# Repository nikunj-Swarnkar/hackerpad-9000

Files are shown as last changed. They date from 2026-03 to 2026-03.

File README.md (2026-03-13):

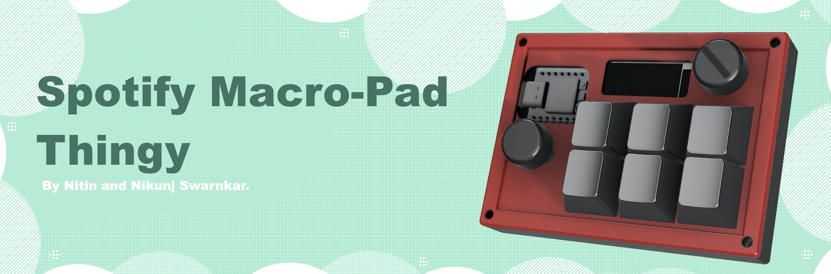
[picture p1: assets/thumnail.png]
thunail


# Spotify Marcro-pad Thingy







A custom key macropad with two rotating dials, 6 customisable keys, and an OLED screen. Basically my iteration of the Spotify car thing — but for your desk.

**Project by [nikunj-Swarnkar](https://github.com/nikunj-Swarnkar)** — Firmware by [Nitin-2468-dev](https://github.com/Nitin-2468-dev)

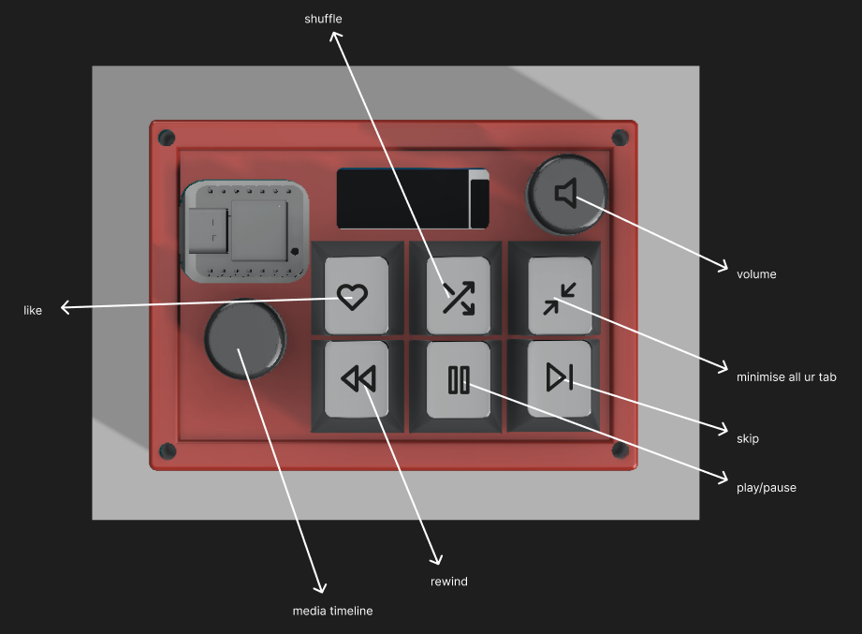
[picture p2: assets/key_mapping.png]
Key mapping


---

## Features

- Two-part case, easy to assemble
- 128×32 OLED display
- 2 × EC11 rotary encoders
- 4 heat-set inserts and bolted case
- 6 mechanical keys

---

## CAD Model

Made in Fusion360. Everything fits together using 4 × M3 bolts and heat-set inserts. The case has two parts: a main body and a front lid.

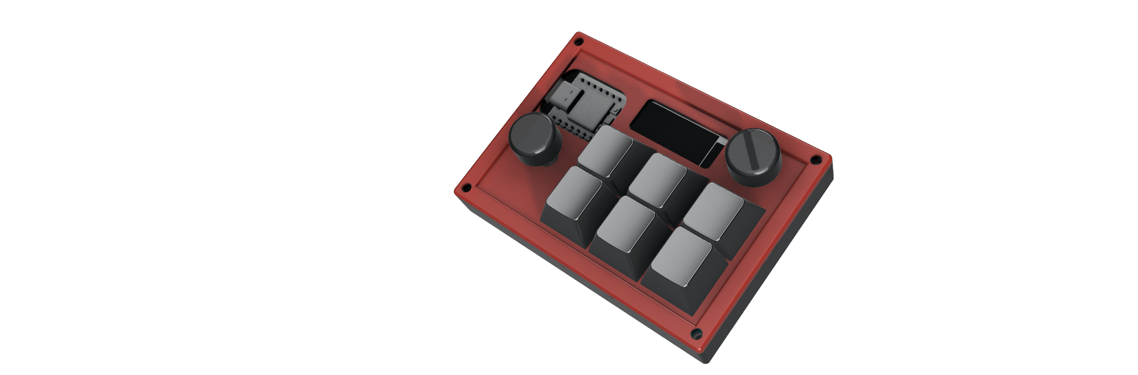
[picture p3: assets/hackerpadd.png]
CAD model


---

## PCB

Made in KiCad.

**Schematic**

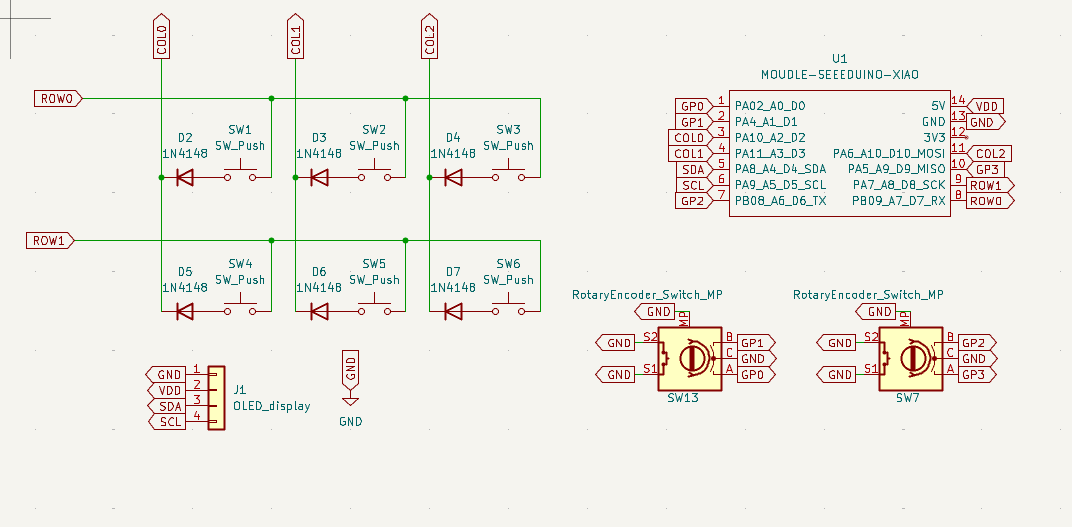
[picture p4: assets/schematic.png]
Schematic


**PCB**

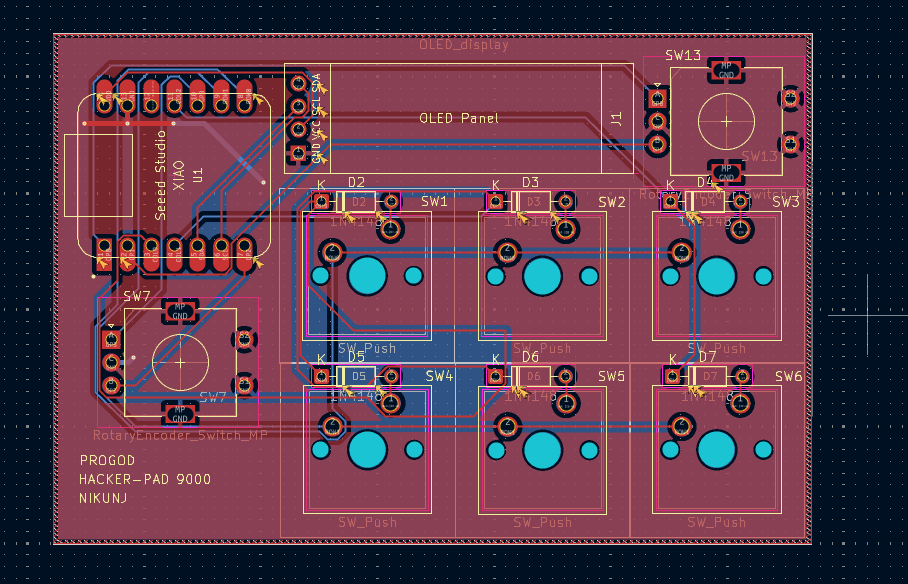
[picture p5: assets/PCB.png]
PCB


Uses MX-style key switches.

---

## Firmware Overview

The Spotify Marcro-pad Thingy runs **[KMK firmware](https://github.com/KMKfw/kmk_firmware)** on a **[Seeed XIAO RP2040](https://wiki.seeedstudio.com/XIAO-RP2040/)**, paired with a **Python bridge application** that connects Spotify playback data to the keyboard over USB. The device behaves like a mini StreamDeck dedicated to music control.

### Playback Controls

| Key | Action |
| --- | --- |
| Play/Pause | Toggle playback |
| Next | Next track |
| Previous | Previous track  |
| Shuffle | Toggle shuffle  |
| Repeat | Toggle repeat |
| Mute | Set volume to 0 |

### Encoder Controls

| Encoder | Function |
| --- | --- |
| Encoder 1 | Track timeline |
| Encoder 2 | Volume |

### Key Layout

```
[ Like ]     [ Shuffle ]    [ Minimize ]
[ Rewind ]   [ Play/Pause ] [ Skip ]
```

---

## OLED Display

### Spotify Screen

```
Spotify
Blinding Lights
████░░░░░░ 1:42
```

Displays song title, playback progress bar, and current playback time.

### Volume Screen

```
Volume
██████░░░░ 60%
```

Displayed when adjusting volume.

### Idle Screen

An animated BongoCat appears when nothing is playing.

---

## Album Art Rendering

Album art is fetched from Spotify and processed by the bridge:

1. Download image
2. Resize to 32×32
3. Convert to monochrome
4. Send bitmap to keyboard

The OLED displays the artwork beside the track information.

---

## System Architecture

```
Spotify App
      ↓
Spotify Web API
      ↓
spotify_bridge.exe (Python)
      ↓
USB Serial
      ↓
KMK Firmware
      ↓
Macropad Hardware
      ↓
OLED Display + Controls
```

The bridge application handles Spotify API communication; the firmware handles hardware interaction.

---

## Serial Protocol

Communication between the firmware and bridge uses a lightweight text protocol:

```
SONG|title|artist|position|duration|tempo
VOL|70
IDLE
COVER|bitmap_data
CMD|NEXT
CMD|PLAY
CMD|SEEK|120
```

---

## Firmware

Written using **KMK (Keyboard Module Kit)** on CircuitPython. Main file: `CIRCUITPY/code.py`

**Responsibilities:**

- Scan key matrix
- Handle rotary encoders
- Communicate with bridge over USB
- Render OLED interface
- Control RGB lighting

### Pin Mapping

**Matrix**

| Function | Pin |
| --- | --- |
| COL 0 | D2 / GP28 |
| COL 1 | D3 / GP29 |
| COL 2 | D10 / GP3 |
| ROW 0 | D7 / GP1  |
| ROW 1 | D8 / GP2  |

**Encoder 1 — Volume**

| Signal | Pin |
| --- | --- |
| A | D0 / GP26 |
| B | D1 / GP27 |

**Encoder 2 — Track Scrub**

| Signal | Pin |
| --- | --- |
| A | D6 / GP0 |
| B | D9 / GP4 |

**OLED**

| Signal | Pin |
| --- | --- |
| SDA | D4 / GP6 |
| SCL | D5 / GP7 |

**RGB LEDs:** DATA → D0 / GP26

---

## Folder Structure

| Path | Description |
| ---- | --- |
| [`LICENSE`](https://github.com/nikunj-Swarnkar/Spotify_marcro_pad_thingy/blob/main/LICENSE) | MIT License |
| [`README.md`](https://github.com/nikunj-Swarnkar/Spotify_marcro_pad_thingy/blob/main/README.md) | This file |
| [`CIRCUITPY/`](https://github.com/nikunj-Swarnkar/Spotify_marcro_pad_thingy/tree/main/CIRCUITPY) | Firmware files copied to the board |
| [`CIRCUITPY/code.py`](https://github.com/nikunj-Swarnkar/Spotify_marcro_pad_thingy/blob/main/CIRCUITPY/code.py) | Main firmware entry point |
| [`CIRCUITPY/display_manager.py`](https://github.com/nikunj-Swarnkar/Spotify_marcro_pad_thingy/blob/main/CIRCUITPY/display_manager.py) | OLED display logic |
| [`CIRCUITPY/duck_animation.py`](https://github.com/nikunj-Swarnkar/Spotify_marcro_pad_thingy/blob/main/CIRCUITPY/duck_animation.py) | Idle duck animation |
| [`CIRCUITPY/rgb_manager.py`](https://github.com/nikunj-Swarnkar/Spotify_marcro_pad_thingy/blob/main/CIRCUITPY/rgb_manager.py) | RGB LED control |
| [`CIRCUITPY/lib/`](https://github.com/nikunj-Swarnkar/Spotify_marcro_pad_thingy/tree/main/CIRCUITPY/lib) | CircuitPython libraries |
| [`spotify_bridge/`](https://github.com/nikunj-Swarnkar/Spotify_marcro_pad_thingy/tree/main/spotify_bridge) | PC bridge application |
| [`spotify_bridge/spotify_bridge.exe`](https://github.com/nikunj-Swarnkar/Spotify_marcro_pad_thingy/blob/main/spotify_bridge/spotify_bridge.exe) | Compiled bridge (no Python required) |
| [`spotify_bridge/code/spotify_bridge.py`](https://github.com/nikunj-Swarnkar/Spotify_marcro_pad_thingy/blob/main/spotify_bridge/code/spotify_bridge.py) | Bridge source code |
| [`spotify_bridge/code/oled_test_app.py`](https://github.com/nikunj-Swarnkar/Spotify_marcro_pad_thingy/blob/main/spotify_bridge/code/oled_test_app.py) | OLED test utility |
| [`spotify_bridge/code/build_exe.py`](https://github.com/nikunj-Swarnkar/Spotify_marcro_pad_thingy/blob/main/spotify_bridge/code/build_exe.py) | Script to compile the bridge |
| [`spotify_bridge/res/config.json.eg`](https://github.com/nikunj-Swarnkar/Spotify_marcro_pad_thingy/blob/main/spotify_bridge/res/config.json.eg) | Example Spotify API config |
| [`spotify_bridge/res/oled_test_app.exe`](https://github.com/nikunj-Swarnkar/Spotify_marcro_pad_thingy/blob/main/spotify_bridge/res/oled_test_app.exe) | Compiled OLED test utility |
| [`spotify_bridge/res/Duck.gif`](https://github.com/nikunj-Swarnkar/Spotify_marcro_pad_thingy/blob/main/spotify_bridge/res/Duck.gif) | Duck idle animation asset |

---

## Installing Firmware

1. Install CircuitPython for the XIAO RP2040:
   [XIAO RP2040 CircuitPython Guide](https://wiki.seeedstudio.com/XIAO-RP2040-with-CircuitPython/)

2. Copy firmware files to the board at `CIRCUITPY/`.

---

## Spotify Bridge

The bridge software connects the keyboard to Spotify.

**Location:** `spotify_bridge/`

**Run:**

```
spotify_bridge.exe
```

Or:

```
python spotify_bridge.py
```

### Spotify API Setup

1. Create an application at the [Spotify Developer Dashboard](https://developer.spotify.com/dashboard)
2. Add the redirect URI: `http://localhost:8888/callback`
3. Copy your credentials into `spotify_bridge/res/config.json`

---

## Running the System

1. Plug the macropad into USB
2. Launch `spotify_bridge.exe`
3. Start Spotify
4. Use the macropad to control playback

---

## Future Improvements

- Audio visualizer on OLED
- RGB BPM lighting improvements
- System tray bridge application
- Multi-service support (YouTube Music, Apple Music)
- Enhanced OLED UI

---

## Bill of Materials

| Qty | Item |
| --- | --- |
| 6×  | Cherry MX switches |
| 6×  | DSA keycaps |
| 4×  | M3×5×4 heat-set inserts |
| 4×  | M3×16mm SHCS bolts |
| 6×  | 1N4148 DO-35 diodes |
| 1×  | 0.91" 128×32 OLED display |
| 2×  | EC11 rotary encoders |
| 1×  | Seeed XIAO RP2040 |
| 1×  | Case (2 printed parts) |

---

## License

[MIT License](https://github.com/nikunj-Swarnkar/Spotify_marcro_pad_thingy/blob/main/LICENSE)

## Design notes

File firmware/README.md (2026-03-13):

# Spotify Macropad with OLED Display

A custom **Spotify control macropad** built using the **Seeed XIAO RP2040**, running **KMK firmware** and powered by a **Python bridge application** that connects Spotify playback data to the keyboard over USB.

The device acts as a **hardware Spotify controller + display**, showing live song information, album art, and animations on a small OLED screen.

Made by [Nitin Swarnkar](https://github.com/Nitin-2468-dev)

---

## Installing and Firmware Setup

This section explains how to install the firmware on the macropad and run the Spotify bridge software.

---

### 1. Install CircuitPython



1. Plug the **Seeed XIAO RP2040** into your computer.
2. Double-tap the **RESET** button on the board. A new drive called *RPI-RP2* will appear:

   

3. Download the CircuitPython firmware for the board:
   https://circuitpython.org/board/seeeduino_xiao_rp2040/

4. Drag the downloaded `.uf2` file onto the **RPI-RP2** drive:

   

   The board will reboot and a new drive will appear named **CIRCUITPY**.

---

### 2. Copy Firmware Files

Open the `CIRCUITPY` drive and copy the following files. The folder should look like:



---

### 3. Setup the Spotify Bridge



Navigate to the bridge folder:

```
spotify_bridge/
```

Run the bridge application:

```
spotify_bridge.exe
```

Or run the Python script directly at `firmware/spotify_bridge/code`:

```
python spotify_bridge.py
```

The bridge connects to the Spotify API and communicates with the keyboard via USB serial.

---

### 4. Configure Spotify API



1. Create a [Spotify Developer](https://developer.spotify.com/dashboard) application.

2. Copy your credentials:

   

3. Add the following redirect URI:

   ```
   http://localhost:8888/callback
   ```

4. Enable the following API:

   ```
   Web API
   ```



---

### 5. Running the System

1. Plug the macropad into USB.
2. Launch `spotify_bridge.exe`.
3. Start Spotify.
4. The OLED display should begin showing track information.

You can now control Spotify using the macropad.

---

### Troubleshooting

**Spotify data not updating**

Make sure:

- Spotify is open
- The bridge application is running
- Authentication completed successfully

---

## Project Goals

This project aims to create a **dedicated hardware controller for Spotify** with the following capabilities:

- Control music playback
- Display currently playing song
- Show playback progress
- Adjust volume
- Scrub through the track
- Display album art
- Animate a BongoCat reacting to music
- Run a lightweight PC companion app

The final result behaves similarly to a **mini StreamDeck specifically for Spotify**.

---

## System Architecture

```
Spotify App
      ↓
Spotify Web API
      ↓
spotify_bridge.exe (Python)
      ↓
USB Serial
      ↓
KMK Firmware
      ↓
Macropad Hardware
      ↓
OLED Display + Controls
```

The bridge software connects Spotify playback data to the keyboard firmware through a serial protocol.

---

## Hardware Components

### Main Controller

- **Seeed XIAO RP2040**

### Input Devices

- 6 × MX-style mechanical switches
- 2 × EC11 rotary encoders

### Display

https://github.com/user-attachments/assets/8e71572c-191a-4422-8621-966e16f79e89

- **0.91" SSD1306 OLED display (128×32)**

### Lighting

- **16 × SK6812 MINI-E RGB LEDs**

### Other Components

- 20 × 1N4148 diodes
- Blank DSA keycaps
- Screws and heat-set inserts

---

## Firmware

Firmware is written using **KMK (Keyboard Module Kit)**, a Python-based keyboard firmware built on **CircuitPython**.

### Why KMK Was Chosen

- Python-based development
- Rapid iteration
- Easy display integration
- Native RP2040 support

### Firmware Responsibilities

- Scan key matrix
- Handle rotary encoders
- Communicate with PC bridge via USB serial
- Render OLED display UI
- Play animations

---

## PC Bridge Software

The PC companion application:

```
spotify_bridge.py
```

Or compiled version:

```
spotify_bridge.exe
```

### Responsibilities

- Connect to Spotify Web API
- Authenticate user
- Retrieve playback data
- Send updates to keyboard
- Receive control commands
- Execute Spotify API actions

The bridge can be packaged as a standalone executable so users **do not need Python installed**.

---

## Spotify Integration

Spotify integration uses the **Spotify Web API** with OAuth authentication.

### Required Permission

```
user-read-playback-state
```

This allows the bridge to read:

- Currently playing track
- Artist
- Playback progress
- Duration
- Album art
- Tempo (BPM)

> **Note:** Some features require **Spotify Premium**.

---

## Serial Protocol

Communication between the keyboard and bridge uses a simple text protocol.

Examples:

```
SONG|title|artist|position|duration|tempo
VOL|70
IDLE
COVER|bitmap_data
CMD|NEXT
CMD|PLAY
CMD|SEEK|120
```

This protocol allows **two-way communication**.

---

## OLED Display UI

The 128×32 OLED shows several screens.

### Spotify Screen

Spotify screen

```
Spotify
Blinding Lights
████░░░░░░ 1:42
```

Displays:

- Song title
- Playback progress bar
- Current playback time
- Cover art

### Volume Screen

```
Volume
██████░░░░ 60%
```

Appears when adjusting volume.

### Idle Screen

Idle screen

```
Duck animation
```

Displayed when nothing is playing.

---

## Album Art Rendering

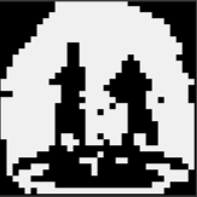
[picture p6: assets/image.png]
Cover


The bridge downloads album art from Spotify. The image is:

1. Downloaded
2. Resized to 32×32 pixels
3. Converted to monochrome
4. Sent to the keyboard as a bitmap

The OLED displays the album cover next to the song information.

---

## Macropad Controls

### Keys

| Key | Action |
| --- | --- |
| Play/Pause | Toggle playback |
| Next | Next track |
| Previous | Previous track  |
| Shuffle | Toggle shuffle  |
| Repeat | Toggle repeat |
| Mute | Set volume to 0 |

### Encoder 1 — Volume

```
Rotate right → volume up
Rotate left  → volume down
```

### Encoder 2 — Track Scrubbing

```
Rotate right → seek forward
Rotate left  → seek backward
```

---

## Display Progress Bar

Playback progress is rendered as a 10-segment bar:

```
1:30  ████░░░░░░
```

Progress is calculated using:

```
progress = position / duration
```

---

## Features

### Core Features

- Spotify playback display
- Playback progress bar
- Hardware volume control
- Track scrubbing
- Shuffle toggle
- Repeat toggle

### UI Features

- OLED interface
- Scrolling song titles
- Album art display
- Duck animations

### System Features

- Two-way serial protocol
- PC companion application
- Standalone executable bridge
- Automatic Spotify authentication
- Token caching
- Auto reconnect USB

---

## Why This Design

This architecture was chosen because KMK firmware provides flexible keyboard development while Python allows quick UI development and API integration.

The bridge software separates Spotify integration from firmware, making the keyboard firmware lightweight and reusable. The result is a **modular system** where firmware handles hardware and the bridge handles network/API logic.

---

## Future Improvements

- Animated audio visualizer
- RGB LEDs reacting to music
- System tray bridge application
- Multi-service support (YouTube Music, Apple Music)
- Better OLED UI layouts

---

## Project Status

- Software architecture completed
- Firmware and bridge logic implemented
- Waiting for hardware components to assemble the physical macropad

---

*Firmware built by **Nitin Swarnkar***

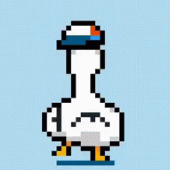
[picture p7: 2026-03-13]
firmware/spotify_bridge/res/Duck.gif

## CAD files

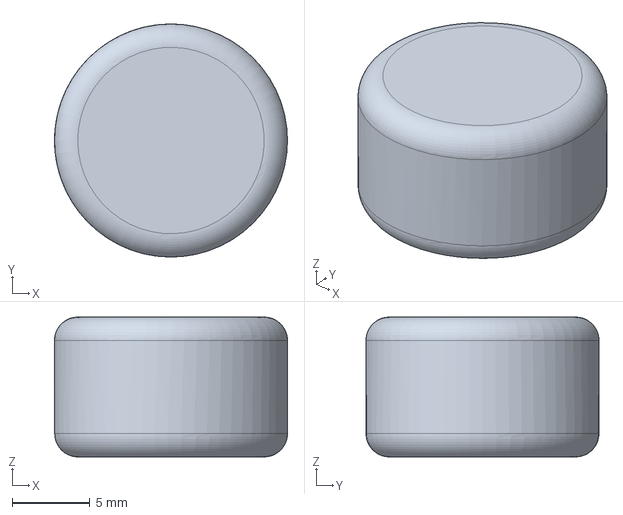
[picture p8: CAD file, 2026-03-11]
production/nob 1.step
15.0 x 15.0 x 9.00 mm

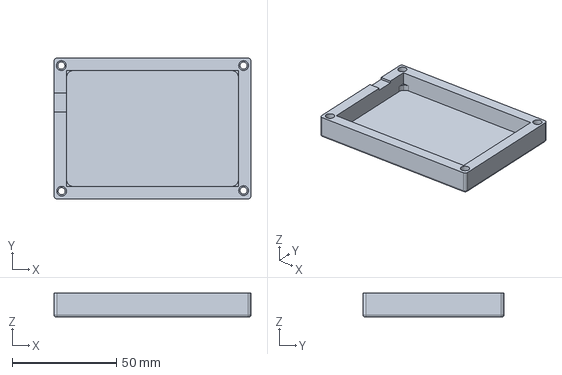
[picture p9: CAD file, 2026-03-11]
production/body.step
94.5 x 67.6 x 11.5 mm

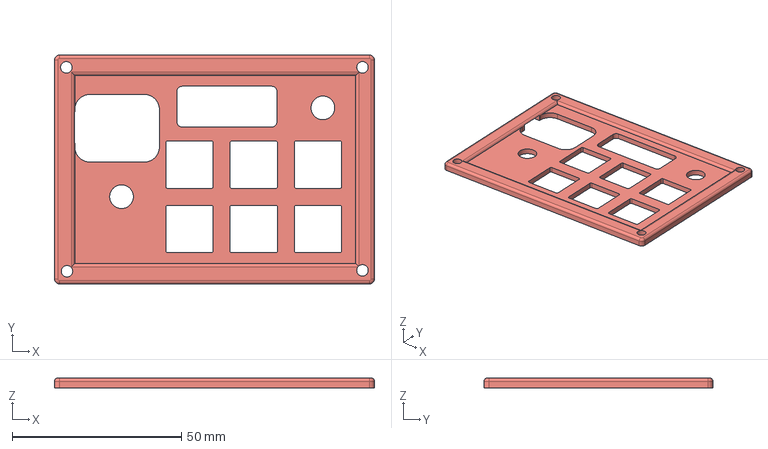
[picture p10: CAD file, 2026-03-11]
production/front.step
94.5 x 67.6 x 3.00 mm

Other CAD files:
production/front lid.step
production/nob 2.step

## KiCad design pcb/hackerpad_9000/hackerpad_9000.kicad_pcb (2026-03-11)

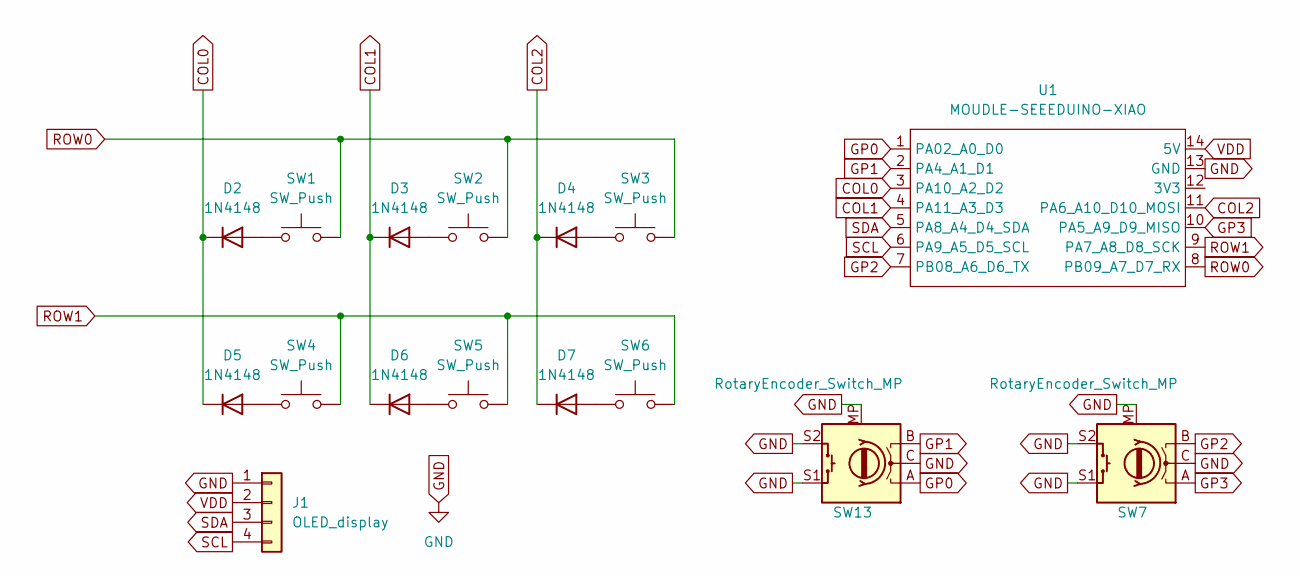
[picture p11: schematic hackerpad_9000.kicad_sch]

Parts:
D2, D3, D4, D5, D6, D7: 1N4148; D_DO-35_SOD27_P7.62mm_Horizontal
J1: OLED_display; SSD1306-0.91-OLED-4pin-128x32
SW1, SW2, SW3, SW4, SW5, SW6: SW_Push; SW_Cherry_MX_1.00u_PCB
SW7, SW13: RotaryEncoder_Switch_MP; RotaryEncoder_Alps_EC11E-Switch_Vertical_H20mm
U1: MOUDLE-SEEEDUINO-XIAO; XIAO-Generic-Hybrid-14P-2.54-21X17.8MM

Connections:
COL0: D2.1 (K), D5.1 (K), U1.3 (PA10_A2_D2)
COL1: D3.1 (K), D6.1 (K), U1.4 (PA11_A3_D3)
COL2: D4.1 (K), D7.1 (K), U1.11 (PA6_A10_D10_MOSI)
GND: J1.1 (GND), SW7.C, SW7.MP, SW7.S1, SW7.S2, SW13.C, SW13.MP, SW13.S1, SW13.S2, U1.13 (GND)
GP0: SW13.A, U1.1 (PA02_A0_D0)
GP1: SW13.B, U1.2 (PA4_A1_D1)
GP2: SW7.B, U1.7 (PB08_A6_D6_TX)
GP3: SW7.A, U1.10 (PA5_A9_D9_MISO)
unnamed: D2.2 (A), SW1.1
unnamed: D3.2 (A), SW2.1
unnamed: D4.2 (A), SW3.1
unnamed: D5.2 (A), SW4.1
unnamed: D6.2 (A), SW5.1
unnamed: D7.2 (A), SW6.1
ROW0: SW1.2, SW2.2, SW3.2, U1.8 (PB09_A7_D7_RX)
ROW1: SW4.2, SW5.2, SW6.2, U1.9 (PA7_A8_D8_SCK)
SCL: J1.4 (SDA), U1.6 (PA9_A5_D5_SCL)
SDA: J1.3 (SCL), U1.5 (PA8_A4_D4_SDA)
VDD: J1.2 (VCC), U1.14 (5V)

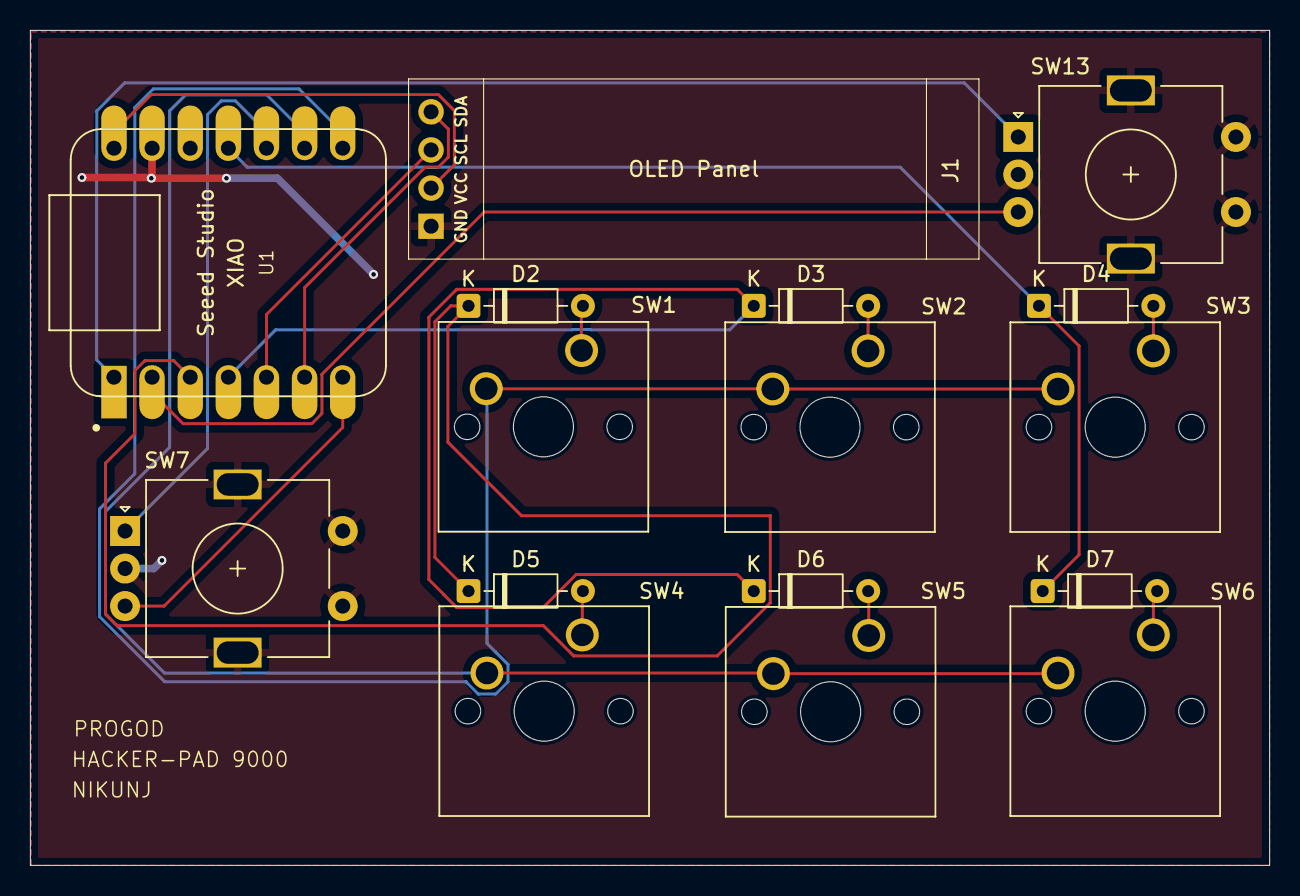
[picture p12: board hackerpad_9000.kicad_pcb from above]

Board: 2 copper layers, 82.6 x 55.6 mm, 16 parts (0 on the bottom side), 19 nets.

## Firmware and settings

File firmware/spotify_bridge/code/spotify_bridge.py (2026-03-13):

"""Spotify ↔ Macropad bridge.

First run:  creates config.json interactively and registers itself in the
            Windows startup registry so it launches automatically at login.
            The device does NOT need to be plugged in yet — the bridge sits
            in the background and connects the moment the macropad appears.

Subsequent runs:  loads config, connects to Spotify, waits for the macropad.
"""

import json
import sys
import time
import winreg
from io import BytesIO
from pathlib import Path
from urllib.request import urlopen

import serial
import serial.tools.list_ports
import spotipy
from PIL import Image
from spotipy.oauth2 import SpotifyOAuth

BAUD_RATE         = 115200
POLL_INTERVAL_S   = 0.35
RECONNECT_DELAY_S = 2.0

APP_NAME = "SpotifyMacropad"


# ---------------------------------------------------------------------------
# Path helpers — work both as a .py script and as a PyInstaller one-file EXE
# ---------------------------------------------------------------------------

def _exe_dir() -> Path:
    """Folder that contains the EXE (or the script when running from source)."""
    if getattr(sys, "frozen", False):
        return Path(sys.executable).parent
    return Path(__file__).parent


def _resource(filename: str) -> Path:
    """Bundled read-only assets (e.g. Duck.gif) extracted by PyInstaller."""
    if getattr(sys, "frozen", False):
        return Path(sys._MEIPASS) / filename          # type: ignore[attr-defined]
    return Path(__file__).parent / filename


def _config_path() -> Path:
    return _exe_dir() / "config.json"


# ---------------------------------------------------------------------------
# First-run config wizard
# ---------------------------------------------------------------------------

def _create_config() -> dict:
    print()
    print("╔══════════════════════════════════════════╗")
    print("║   Spotify Macropad — First-Run Setup     ║")
    print("╚══════════════════════════════════════════╝")
    print()
    print("You need a Spotify developer app to continue.")
    print("  1. Go to  https://developer.spotify.com/dashboard")
    print("  2. Create an app (any name/description)")
    print("  3. Add   http://127.0.0.1:8888/callback   as a Redirect URI")
    print("  4. Copy the Client ID and Client Secret below")
    print()

    client_id     = input("  CLIENT_ID     : ").strip()
    client_secret = input("  CLIENT_SECRET : ").strip()
    redirect_uri  = (
        input("  REDIRECT_URI  [http://127.0.0.1:8888/callback]: ").strip()
        or "http://127.0.0.1:8888/callback"
    )

    config = {
        "CLIENT_ID":     client_id,
        "CLIENT_SECRET": client_secret,
        "REDIRECT_URI":  redirect_uri,
    }

    path = _config_path()
    path.write_text(json.dumps(config, indent=2), encoding="utf-8")
    print(f"\n  ✓ Config saved to {path}")
    return config


def load_config() -> dict:
    path = _config_path()
    if not path.exists():
        config = _create_config()
        _register_startup()   # register only on first run
        return config

    with path.open("r", encoding="utf-8") as f:
        return json.load(f)


# ---------------------------------------------------------------------------
# Windows startup registry — bridge auto-launches at login
# ---------------------------------------------------------------------------

def _startup_exe() -> str:
    if getattr(sys, "frozen", False):
        return str(sys.executable)
    # Running from source: tell Windows to call python with this script
    return f'"{sys.executable}" "{Path(__file__).resolve()}"'


def _register_startup() -> None:
    try:
        key = winreg.OpenKey(
            winreg.HKEY_CURRENT_USER,
            r"Software\Microsoft\Windows\CurrentVersion\Run",
            0,
            winreg.KEY_SET_VALUE,
        )
        winreg.SetValueEx(key, APP_NAME, 0, winreg.REG_SZ, _startup_exe())
        winreg.CloseKey(key)
        print("  ✓ Bridge registered in Windows startup")
        print("    (it will launch automatically at login and wait for the macropad)")
    except Exception as exc:
        print(f"  ! Could not register startup entry: {exc}")


def _unregister_startup() -> None:
    try:
        key = winreg.OpenKey(
            winreg.HKEY_CURRENT_USER,
            r"Software\Microsoft\Windows\CurrentVersion\Run",
            0,
            winreg.KEY_SET_VALUE,
        )
        winreg.DeleteValue(key, APP_NAME)
        winreg.CloseKey(key)
        print("Removed from Windows startup.")
    except FileNotFoundError:
        print("Not registered — nothing to remove.")
    except Exception as exc:
        print(f"Could not remove startup entry: {exc}")


# ---------------------------------------------------------------------------
# Spotify client
# ---------------------------------------------------------------------------

def build_spotify_client(config: dict) -> spotipy.Spotify:
    cache_path = _exe_dir() / ".spotify_cache"
    return spotipy.Spotify(
        auth_manager=SpotifyOAuth(
            client_id=config["CLIENT_ID"],
            client_secret=config["CLIENT_SECRET"],
            redirect_uri=config["REDIRECT_URI"],
            scope=" ".join([
                "user-read-playback-state",
                "user-modify-playback-state",
            ]),
            cache_path=str(cache_path),
            open_browser=True,
        )
    )


# ---------------------------------------------------------------------------
# Serial port helpers
# ---------------------------------------------------------------------------

def find_port() -> str | None:
    ports = list(serial.tools.list_ports.comports())
    preferred = ("XIAO", "RP2040", "CIRCUITPYTHON", "USB")
    for p in ports:
        if any(t in (p.description or "").upper() for t in preferred):
            return p.device
    return ports[0].device if ports else None


def open_serial_with_retry(forced_port: str | None = None) -> serial.Serial:
    while True:
        port = forced_port or find_port()
        if port:
            try:
                print(f"Connecting → {port} …")
                return serial.Serial(port, BAUD_RATE, timeout=0.02)
            except Exception as exc:
                print(f"  Failed: {exc}")
        else:
            print("Macropad not found — waiting …")
        time.sleep(RECONNECT_DELAY_S)


# ---------------------------------------------------------------------------
# Album art
# ---------------------------------------------------------------------------

def build_cover_hex(url: str | None) -> str | None:
    if not url:
        return None

    with urlopen(url, timeout=10) as resp:
        image_bytes = resp.read()

    img = Image.open(BytesIO(image_bytes)).convert("L").resize((32, 32))
    bw  = img.point(lambda p: 255 if p > 127 else 0, mode="1")

    pixels = bw.load()
    packed = bytearray(128)
    for page in range(4):
        for x in range(32):
            value = 0
            for bit in range(8):
                if pixels[x, page * 8 + bit] == 255:
                    value |= 1 << bit
            packed[page * 32 + x] = value

    return packed.hex()


# ---------------------------------------------------------------------------
# Serial I/O
# ---------------------------------------------------------------------------

def safe_write(ser: serial.Serial, text: str) -> None:
    ser.write((text + "\n").encode("utf-8"))


def handle_command(sp: spotipy.Spotify, playback: dict | None, cmd_line: str) -> None:
    parts = cmd_line.strip().split("|")
    if len(parts) < 2 or parts[0] != "CMD":
        return

    action = parts[1]

    if action == "NEXT":
        sp.next_track()
    elif action == "PREV":
        sp.previous_track()
    elif action == "PLAY_PAUSE":
        if playback and playback.get("is_playing"):
            sp.pause_playback()
        else:
            sp.start_playback()
    elif action == "SHUFFLE":
        sp.shuffle(not bool(playback and playback.get("shuffle_state")))
    elif action == "REPEAT":
        order   = ["off", "context", "track"]
        cur     = (playback or {}).get("repeat_state", "off")
        sp.repeat(order[(order.index(cur) + 1) % len(order)] if cur in order else "off")
    elif action == "MUTE":
        sp.volume(0)
    elif action == "VOL_REL" and len(parts) >= 3:
        delta   = int(parts[2])
        current = int((playback or {}).get("device", {}).get("volume_percent", 0))
        sp.volume(max(0, min(100, current + delta)))
    elif action == "SEEK_REL" and len(parts) >= 3:
        delta_s  = int(parts[2])
        progress = int((playback or {}).get("progress_ms", 0))
        duration = int((playback or {}).get("item", {}).get("duration_ms", 0))
        sp.seek_track(max(0, min(duration, progress + delta_s * 1000)))


def poll_commands(sp, ser, playback) -> None:
    while ser.in_waiting:
        line = ser.readline().decode("utf-8", errors="ignore").strip()
        if line:
            try:
                handle_command(sp, playback, line)
            except Exception as exc:
                print(f"Command error [{line}]: {exc}")


def read_tempo(_sp, _track_id) -> int:
    # audio_features deprecated for new apps (returns 403) — return 0
    return 0


def send_playback_state(sp, ser, cache: dict) -> None:
    playback = sp.current_playback()
    poll_commands(sp, ser, playback)

    if playback and playback.get("item"):
        track       = playback["item"]
        song        = (track.get("name") or "").replace("|", "/")
        artists     = track.get("artists") or []
        artist_name = ((artists[0].get("name") if artists else "") or "").replace("|", "/")
        position    = int((playback.get("progress_ms") or 0) / 1000)
        duration    = int((track.get("duration_ms") or 0) / 1000)
        track_id    = track.get("id") or ""

        if track_id and track_id != cache["track_id"]:
            cache["track_id"] = track_id
            cache["tempo"]    = read_tempo(sp, track_id)
            images            = track.get("album", {}).get("images", [])
            image_url         = images[-1]["url"] if images else None
            try:
                cache["cover"] = build_cover_hex(image_url) if image_url else None
            except Exception as exc:
                print(f"Cover error: {exc}")
                cache["cover"] = None

        safe_write(ser, f"SONG|{song}|{artist_name}|{position}|{duration}|{cache['tempo']}")
        if cache["cover"]:
            safe_write(ser, f"COVER|{cache['cover']}")
    else:
        safe_write(ser, "IDLE")


# ---------------------------------------------------------------------------
# Main
# ---------------------------------------------------------------------------

def main() -> None:
    import argparse

    parser = argparse.ArgumentParser(description="Spotify Macropad Bridge")
    parser.add_argument("--port",      help="Force a specific COM port (e.g. COM6)")
    parser.add_argument("--uninstall", action="store_true",
                        help="Remove bridge from Windows startup and exit")
    args = parser.parse_args()

    if args.uninstall:
        _unregister_startup()
        return

    config = load_config()
    print("\nAuthenticating with Spotify …")
    sp = build_spotify_client(config)

    ser   = open_serial_with_retry(args.port)
    cache = {"track_id": "", "tempo": 0, "cover": None}

    print("Bridge running. Press Ctrl+C to stop.\n")

    while True:
        try:
            if not ser.is_open:
                ser = open_serial_with_retry(args.port)
            send_playback_state(sp, ser, cache)
            time.sleep(POLL_INTERVAL_S)
        except KeyboardInterrupt:
            print("\nStopping bridge.")
            break
        except Exception as exc:
            print(f"Bridge error: {exc}")
            try:
                ser.close()
            except Exception:
                pass
            time.sleep(RECONNECT_DELAY_S)
            ser = open_serial_with_retry(args.port)


if __name__ == "__main__":
    main()

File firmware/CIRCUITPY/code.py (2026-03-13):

import time

import board
import usb_cdc

from kmk.kmk_keyboard import KMKKeyboard
from kmk.keys import KC, make_key
from kmk.modules.encoder import EncoderHandler
from kmk.scanners import DiodeOrientation

from display_manager import DisplayManager
from rgb_manager import RGBManager

DRAW_INTERVAL_S = 0.05

keyboard = KMKKeyboard()
keyboard.col_pins = (board.GP26, board.GP27, board.GP28)
keyboard.row_pins = (board.GP6, board.GP7)
keyboard.diode_orientation = DiodeOrientation.COL2ROW

encoder_handler = EncoderHandler()
encoder_handler.pins = (
    (board.GP0, board.GP1),  # volume
    (board.GP2, board.GP3),  # scrub
)
keyboard.modules.append(encoder_handler)

serial_data = usb_cdc.data
display = DisplayManager()
rgb = RGBManager(board.GP29, count=16, brightness=0.25)

_last_draw = 0.0
_last_pressed = 0


def _send_command(command):
    try:
        serial_data.write((command + "\n").encode("utf-8"))
    except Exception:
        pass


def _cmd_press(message):
    def _handler(_key, _keyboard, *args, **kwargs):
        _send_command(message)
        display.note_key_activity()

    return _handler


# Custom actions routed to the bridge for Spotify API control.
make_key(names=("SP_PLAY",), on_press=_cmd_press("CMD|PLAY_PAUSE"))
make_key(names=("SP_NEXT",), on_press=_cmd_press("CMD|NEXT"))
make_key(names=("SP_PREV",), on_press=_cmd_press("CMD|PREV"))
make_key(names=("SP_SHUF",), on_press=_cmd_press("CMD|SHUFFLE"))
make_key(names=("SP_REPT",), on_press=_cmd_press("CMD|REPEAT"))
make_key(names=("SP_MUTE",), on_press=_cmd_press("CMD|MUTE"))
make_key(names=("VOL_UP_CMD",), on_press=_cmd_press("CMD|VOL_REL|2"))
make_key(names=("VOL_DN_CMD",), on_press=_cmd_press("CMD|VOL_REL|-2"))
make_key(names=("SEEK_FWD",), on_press=_cmd_press("CMD|SEEK_REL|5"))
make_key(names=("SEEK_BACK",), on_press=_cmd_press("CMD|SEEK_REL|-5"))

keyboard.keymap = [[
    KC.SP_MUTE,
    KC.SP_SHUF,
    KC.SP_REPT,
    KC.SP_PREV,
    KC.SP_PLAY,
    KC.SP_NEXT,
]]

encoder_handler.map = [
    ((KC.VOL_DN_CMD, KC.VOL_UP_CMD),),
    ((KC.SEEK_BACK, KC.SEEK_FWD),),
]


def _safe_read_serial_line():
    if not serial_data.in_waiting:
        return None

    try:
        line = serial_data.readline()
        if not line:
            return None
        return line.decode("utf-8", errors="ignore").strip()
    except Exception:
        return None


def after_matrix_scan(_keyboard):
    global _last_draw, _last_pressed

    msg = _safe_read_serial_line()
    if msg:
        display.handle_message(msg)
        if msg.startswith("SONG|"):
            parts = msg.split("|")
            if len(parts) >= 6:
                try:
                    rgb.set_bpm(int(parts[5]))
                except ValueError:
                    rgb.set_bpm(0)
        elif msg.startswith("IDLE"):
            rgb.set_bpm(0)

    pressed = len(keyboard.keys_pressed)
    if pressed > _last_pressed:
        display.note_key_activity()
    _last_pressed = pressed

    now = time.monotonic()
    if now - _last_draw >= DRAW_INTERVAL_S:
        display.draw()
        rgb.update()
        _last_draw = now


keyboard.after_matrix_scan = after_matrix_scan

if __name__ == "__main__":
    keyboard.go()
